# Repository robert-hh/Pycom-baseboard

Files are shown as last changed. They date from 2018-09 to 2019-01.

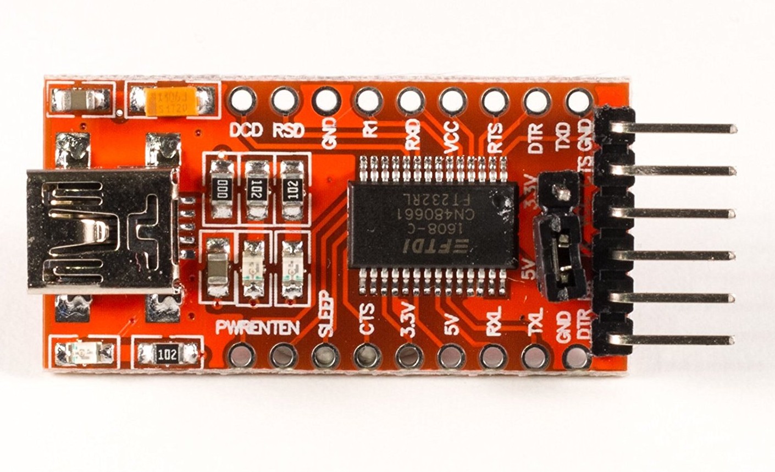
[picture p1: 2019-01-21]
FTDI_Adapter.jpg

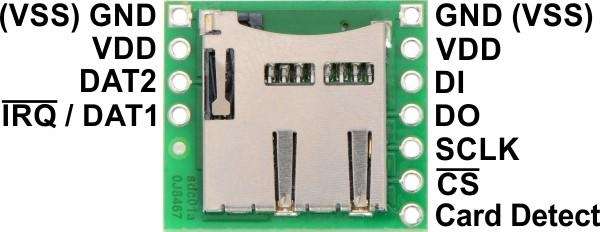
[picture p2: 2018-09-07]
pololu_SD_breakout.jpg

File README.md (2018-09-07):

Baseboard: Simple baseboard for PyCom development modules

This board does not use SMD components. Instead low price modules for the USB/UART
bridge and the SD card adapter are used. The USB/UART bridge is the red FTDI
module, which are sold at prices of $1.5 on. It has to be set to 3.3 V.
The SD card module is the one of Pololu, which is also widely available.
Pictures of the modules are included in the repository. Depending on the
soldered connectors, the board can also be used for WiPy1. Artwork on the board indicates, how the Pycom modules have to be inserted.

The board also carries the two transistor logic used by espressif to switch into
bootstrap mode. The Pycom command line updater pycom-fwtool-cli supports that
with the -r option. The graphical variant does not. If you are building The
firmware yourself, you have to change application.mk at the command for
flashing. Change it into:

  ESPTOOLPY_SERIAL = $(ESPTOOLPY) --port $(ESPPORT) --baud $(ESPBAUD)

especially, remove  "--before no_reset --after no_reset"

Also on the board:
- connections for a reset button, if the board is placed into a closed box.
- A JST2 connector for a battery. There is no charging circuit on the board,
but a diode is foreseen to decouple the battery from the USB/UART bridge. If
you do not need that, solder a wire. Depending on your preference, a Schottky
diode or a silicon diode can be used. Schottky diodes have a substantial
reverse current.  

The metal areas at the mounting holes are connected to GND. That is favorable
if you put the whole board into a metal box, used as ground plane for a Lora or
LTE antenna. If that gets a problem, use Nylon screws.

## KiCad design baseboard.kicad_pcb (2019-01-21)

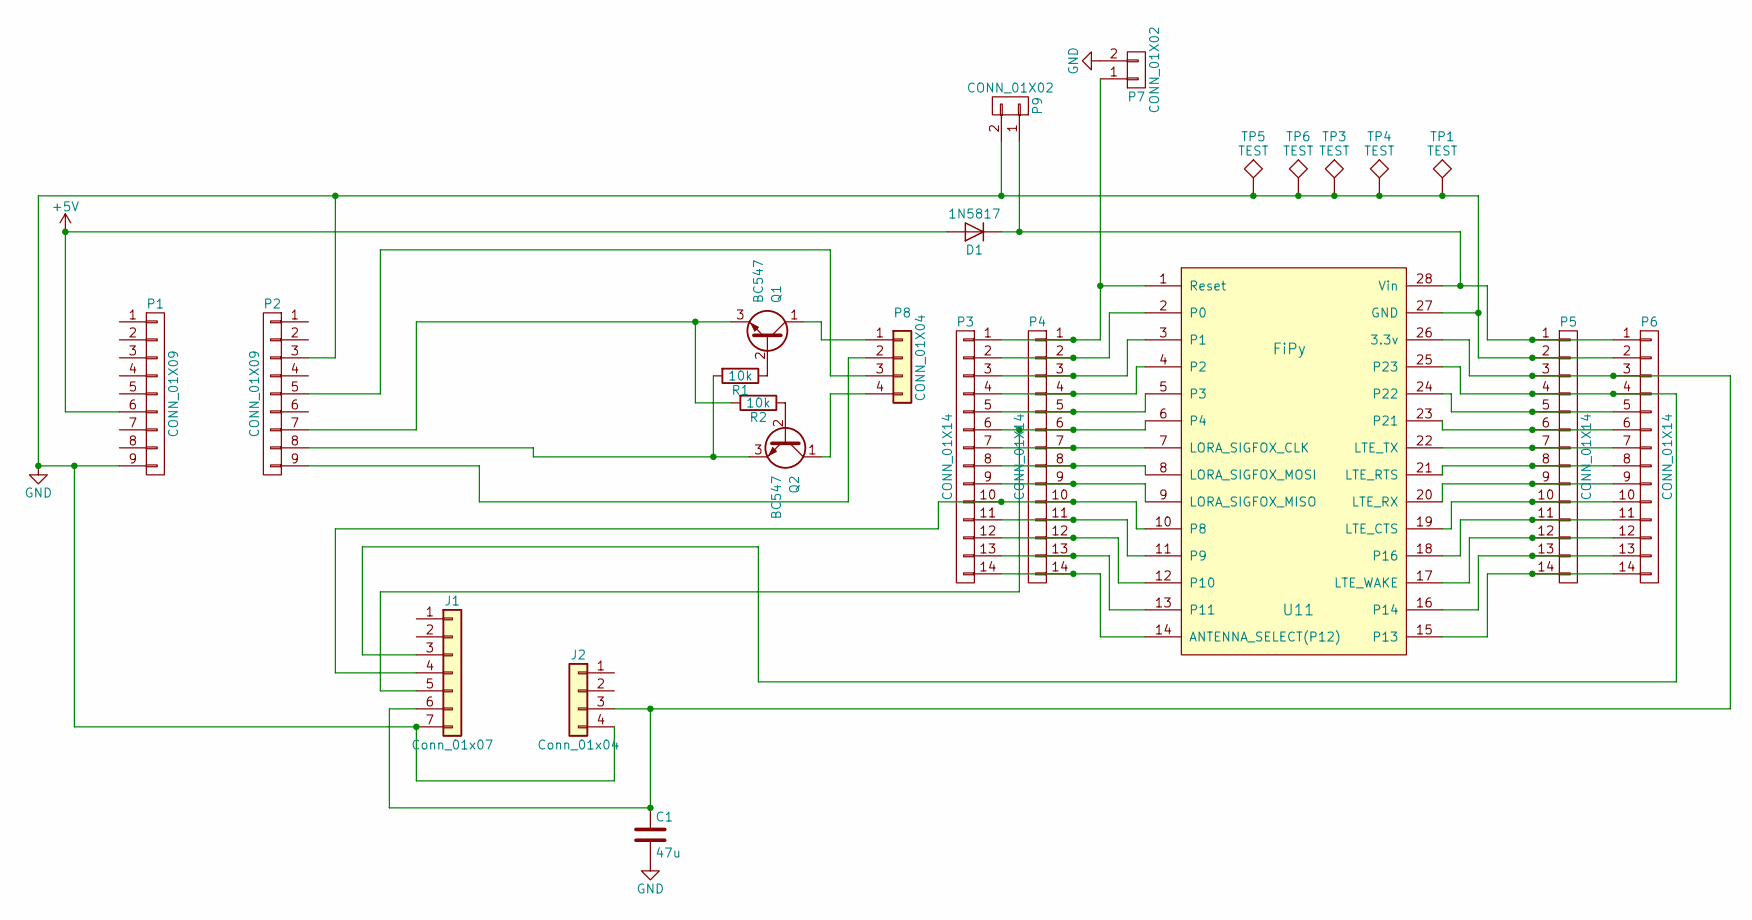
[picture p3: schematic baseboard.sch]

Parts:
C1: 47u; CP_Radial_D6.3mm_P2.50mm
D1: 1N5817; D_DO-41_SOD81_P10.16mm_Horizontal
J1: Conn_01x07; Socket_Strip_Straight_1x07_Pitch2.54mm
J2: Conn_01x04; Socket_Strip_Straight_1x04_Pitch2.54mm
P1, P2: CONN_01X09; Socket_Strip_Straight_1x09_Pitch2.54mm
P3, P4, P5, P6: CONN_01X14; Socket_Strip_Straight_1x14_Pitch2.54mm
P7: CONN_01X02; SW_Tactile_SPST_Angled_PTS645Vx58-2LFS
P8: CONN_01X04; Socket_Strip_Straight_1x04_Pitch2.54mm
P9: CONN_01X02; JST_PH_S2B-PH-K_02x2.00mm_Angled
Q1, Q2: BC547; TO-92_Inline_Narrow_Oval
R1, R2: 10k; R_Axial_DIN0207_L6.3mm_D2.5mm_P10.16mm_Horizontal
TP1: TEST; Socket_Strip_Straight_1x01_Pitch2.54mm
TP3, TP4, TP5, TP6: TEST; MountingHole_3.2mm_M3_Pad_Via
U11: FiPy; LoPy_with_headers

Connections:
+5V: D1.2 (A), P1.6
GND: C1.2, J1.7, J2.4, P1.9, P2.3, P5.2, P6.2, P7.2, P9.2, TP1.1, TP3.1, TP4.1, TP5.1, TP6.1, U11.27 (GND)
unnamed: C1.1, J1.6, J2.3, P5.3, P6.3, U11.26 (3.3v)
unnamed: D1.1 (K), P5.1, P6.1, P9.1, U11.28 (Vin)
unnamed: J1.3, P5.4, P6.4, U11.25 (P23)
unnamed: J1.4, P3.10, P4.10, U11.10 (P8)
unnamed: J1.5, P3.6, P4.6, U11.6 (P4)
unnamed: P2.5, P8.3
unnamed: P2.7, Q1.3 (E), R2.2
unnamed: P2.8, Q2.3 (E), R1.2
unnamed: P2.9, P8.2
unnamed: P3.1, P4.1, P7.1, U11.1 (Reset)
unnamed: P3.2, P4.2, U11.2 (P0)
unnamed: P3.3, P4.3, U11.3 (P1)
unnamed: P3.4, P4.4, U11.4 (P2)
unnamed: P3.5, P4.5, U11.5 (P3)
unnamed: P3.7, P4.7, U11.7 (LORA_SIGFOX_CLK)
unnamed: P3.8, P4.8, U11.8 (LORA_SIGFOX_MOSI)
unnamed: P3.9, P4.9, U11.9 (LORA_SIGFOX_MISO)
unnamed: P3.11, P4.11, U11.11 (P9)
unnamed: P3.12, P4.12, U11.12 (P10)
unnamed: P3.13, P4.13, U11.13 (P11)
unnamed: P3.14, P4.14, U11.14 (ANTENNA_SELECT(P12))
unnamed: P5.5, P6.5, U11.24 (P22)
unnamed: P5.6, P6.6, U11.23 (P21)
unnamed: P5.7, P6.7, U11.22 (LTE_TX)
unnamed: P5.8, P6.8, U11.21 (LTE_RTS)
unnamed: P5.9, P6.9, U11.20 (LTE_RX)
unnamed: P5.10, P6.10, U11.19 (LTE_CTS)
unnamed: P5.11, P6.11, U11.18 (P16)
unnamed: P5.12, P6.12, U11.17 (LTE_WAKE)
unnamed: P5.13, P6.13, U11.16 (P14)
unnamed: P5.14, P6.14, U11.15 (P13)
unnamed: P8.1, Q1.1 (C)
unnamed: P8.4, Q2.1 (C)
unnamed: Q1.2 (B), R1.1
unnamed: Q2.2 (B), R2.1

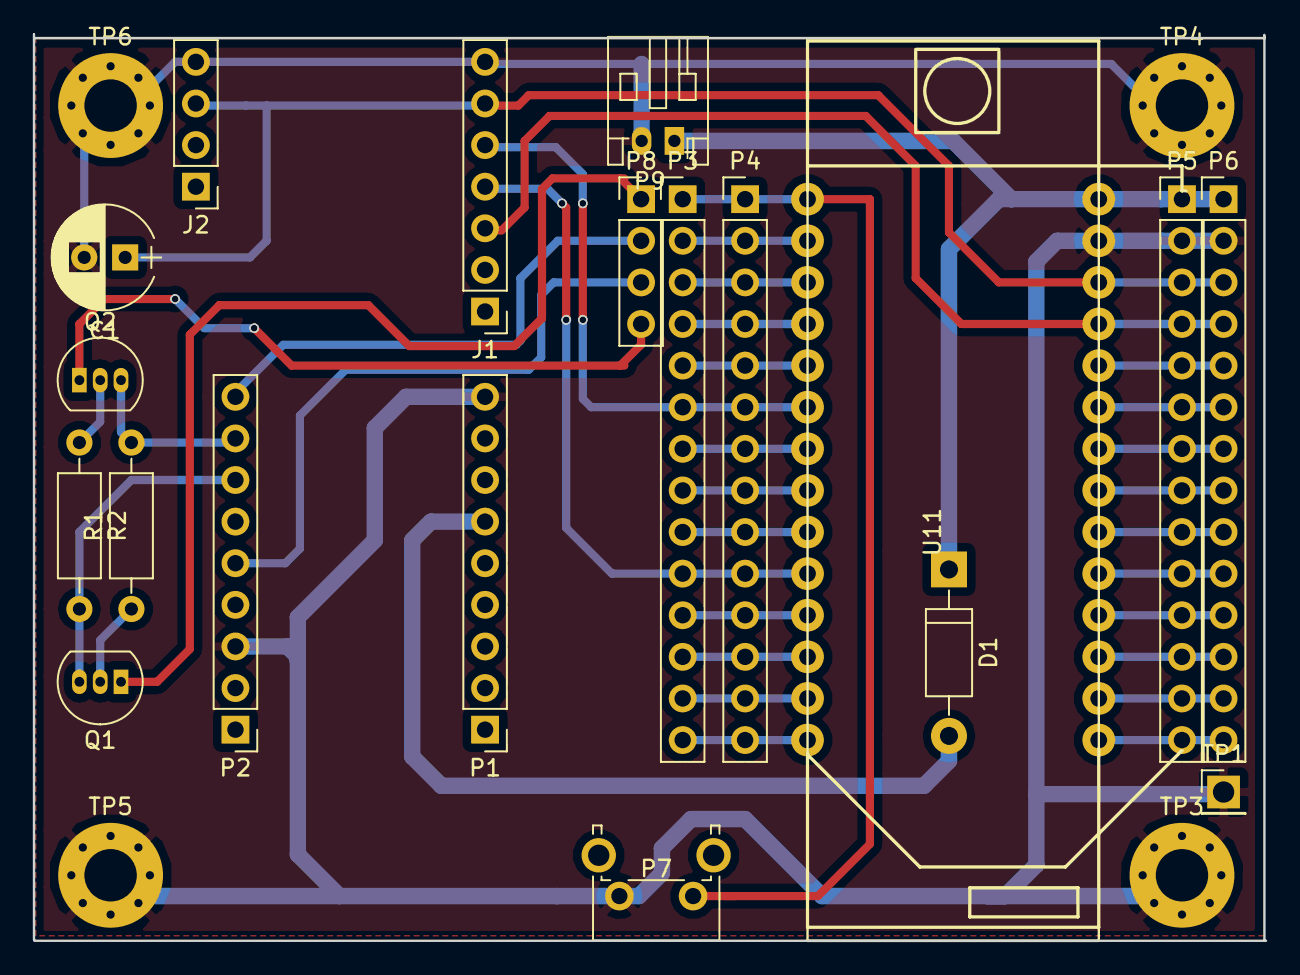
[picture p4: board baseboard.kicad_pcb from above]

Board: 2 copper layers, 75.2 x 55.4 mm, 23 parts (0 on the bottom side), 37 nets.

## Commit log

2018-09-07 baseboard: Simple baseboard for PyCom development modules
    This board does not use SMD circuits. Instead low price modules for the USB/UART
    bridge and the SD card adapter are used. The USB/UART bridge is the red FTDI
    module, which are sold at prices of $1.5 on. The SD card module is the one of
    Pololu, which is also widely available. Pictures of the modules are included
    in the repository. Depending on the soldered connectors, the board can also
    be used for WiPy1. Artwork on the board indicates, how the Pycom modules have
    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
    [baseboard.kicad_pcb, baseboard.sch]
2019-01-21 Some changes after HD reorg:
    - Fixed the -pro file
    - jpg file size change
    [baseboard.kicad_pcb]
